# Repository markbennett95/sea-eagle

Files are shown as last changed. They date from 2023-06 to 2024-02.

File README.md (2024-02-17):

# BCA Sea Eagle Distortion

A multi-stage distortion pedal designed in conjunction with Nick Earle. The inspiration was a tight, heavy, Fall out boy-style rhythm tone. It features a dual-gang gain pot, an active 3-band EQ, and several pre-gain tone shaping switches. It is powered by our standard +-15V power supply, and uses a series of current sources to bias the various JFET stages.

## v1.0.0-build
1590BB enclosure with pots for Gain, Bass, Middle, Treble, Volume, and switches for bright, tight/fat, and high/low input gain.

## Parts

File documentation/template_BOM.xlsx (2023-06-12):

Weather Man v2.1.2 BOM - Nov 2021
Designation | Quantity | Designator
MMBFJ201 | 4 | Q1,Q2,Q3,Q4
47R | 1 | R30
1k | 5 | R4,R7,R20,R22,R25
2.7k | 2 | R6,R27
4.7k | 1 | R19
6.8k | 3 | R17,R29,R33
10k | 2 | R16,R21
12k | 1 | R9
33k | 2 | R11,R15
39k | 1 | R13
68k | 2 | R2,R34
100k | 2 | R31,R32
220k | 1 | R18
470k | 1 | R12
1M | 7 | R1,R3,R5,R10,R14,R24,R26
1N914 | 4 | D3,D1,D2,D4
1N4001 | 1 | D5
100pF | 3 | C1,C10,C12
100nF | 1 | C23
NJM4580 | 1 | U1
1nF | 2 | C3,C7
4.7nF | 1 | C16
6.8nF | 3 | C2,C21
10nF | 4 | C9,C8,C14,C20
47nF | 2 | C13,C17
0.1uF | 5 | C4,C5,C11,C15,C19
100uF | 2 | C22,C24
25kB | 2 | RV1,RV4
100kA | 1 | RV2
100kB | 2 | RV3,RV5
50kB | 1 | RV6
SW_SPDT_DIP | 1 | SW1
SW_SPDT | 1 | SW2

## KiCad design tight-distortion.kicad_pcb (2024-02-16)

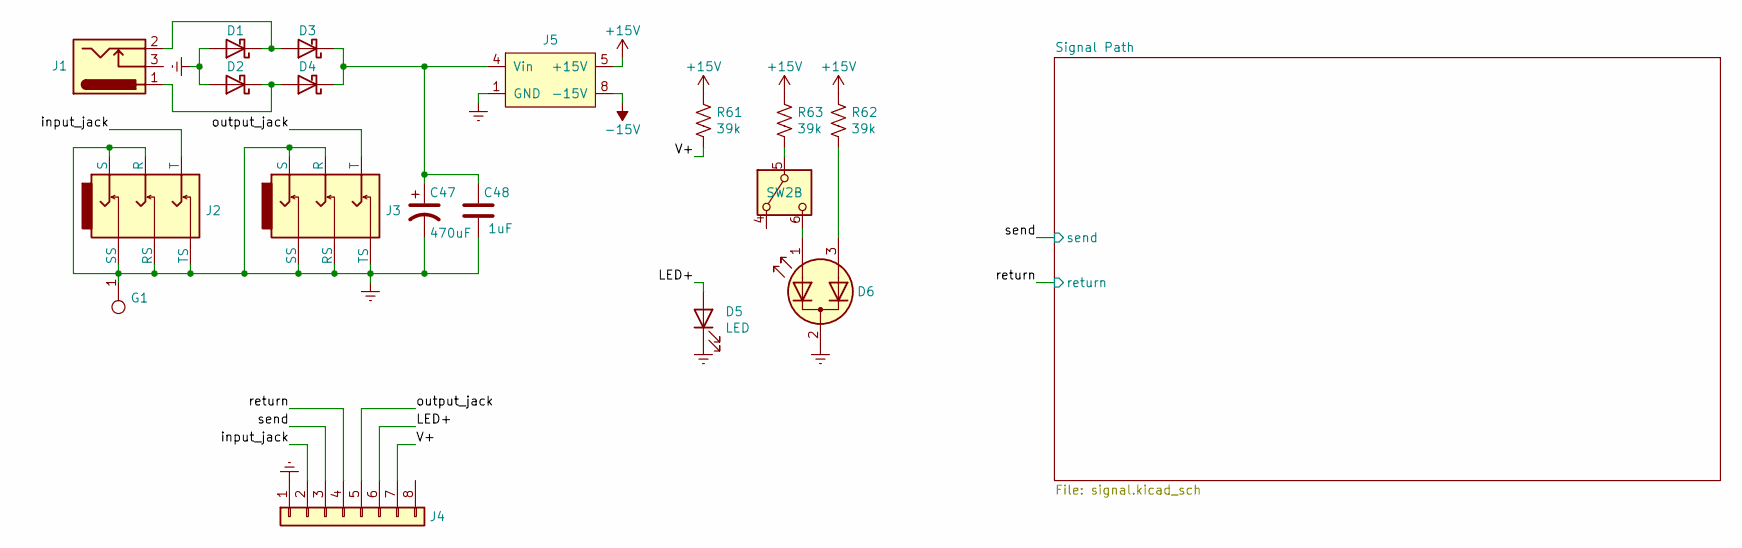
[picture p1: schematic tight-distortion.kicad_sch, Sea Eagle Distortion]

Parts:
C47: 470uF; CP_Radial_D8.0mm_P3.50mm
C48: 1uF; C_0805_2012Metric_Pad1.18x1.45mm_HandSolder
D1, D2, D3, D4: 1N5819; D_SOD-123
D5: LED; LED_D5.0mm
D6: LED_Dual_AAK; LED_D5.0mm-3
G1: GNDSpring; Keystone_628
J1: Barrel_Jack_Switch; DC_Jack_DC005
J2, J3: AudioJack_TRS; Rean_NYS215
J4: Conn_01x08; Pin_Header_Straight_1x08_Pitch2.54mm
J5: power-module; Power-module
R61, R62, R63: 39k; R_L3.6mm_D1.6mm_P5.00mm_Horizontal
SW2: SW_DPDT_x2; Pin_Header_Straight_1x06_Pitch2.54mm

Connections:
+15V: J5.5 (+15V), R61.1, R62.1, R63.1; also elsewhere on the board
-15V: J5.8 (-15V); also elsewhere on the board
/LED+: D5.2 (A), J4.6
/V+: J4.7, R61.2
/input_jack: J2.1 (T), J4.2
/output_jack: J3.1 (T), J4.5
/return: J4.4; also elsewhere on the board
/send: J4.3; also elsewhere on the board
Earth: C47.2, C48.2, D1.2 (A), D2.2 (A), D5.1 (K), D6.2 (K), G1.1, J2.2 (R), J2.3 (S), J2.4 (TS), J2.5 (RS), J2.6 (SS), J3.2 (R), J3.3 (S), J3.4 (TS), J3.5 (RS), J3.6 (SS), J4.1, J5.1 (GND); also elsewhere on the board
unnamed: D1.1 (K), D3.2 (A), J1.2
unnamed: D2.1 (K), D4.2 (A), J1.1
unnamed: C47.1, C48.1, D3.1 (K), D4.1 (K), J5.4 (Vin)
unnamed: D6.1 (A1), SW2.6 (C)
unnamed: D6.3 (A2), R62.2
unnamed: R63.2, SW2.5 (B)

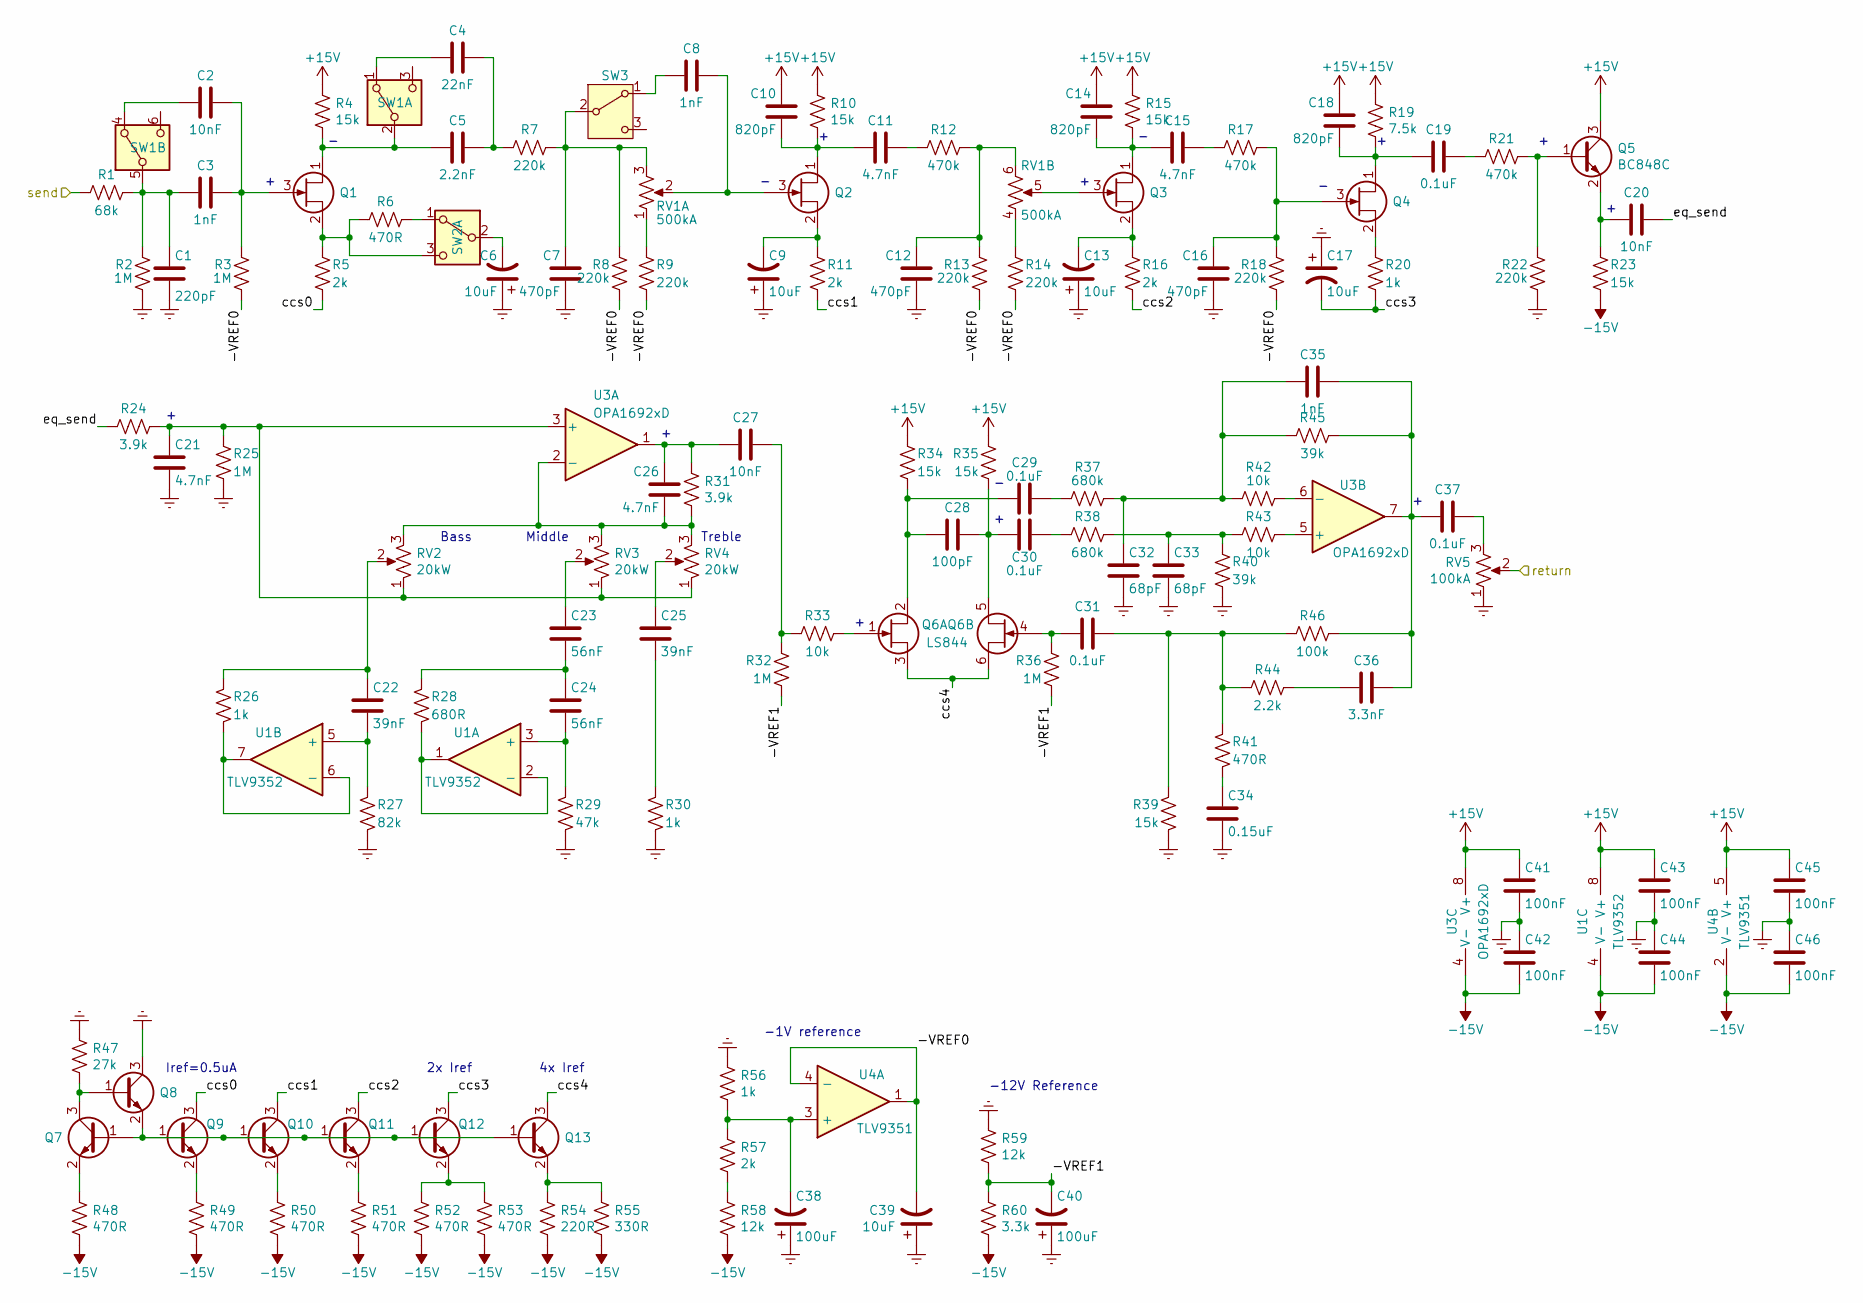
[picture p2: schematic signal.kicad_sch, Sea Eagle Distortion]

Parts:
C1: 220pF; C_0603_1608Metric_Pad1.08x0.95mm_HandSolder
C2, C20, C27: 10nF; C_Film_L7.2mm_W2.5mm_P5.00mm
C3, C8, C35: 1nF; C_Film_L7.2mm_W2.5mm_P5.00mm
C4: 22nF; C_Film_L7.2mm_W2.5mm_P5.00mm
C5: 2.2nF; C_Film_L7.2mm_W2.5mm_P5.00mm
C6, C9, C13, C17, C39: 10uF; CP_Radial_D4.0mm_P1.50mm
C7, C12, C16: 470pF; C_0603_1608Metric_Pad1.08x0.95mm_HandSolder
C10, C14, C18: 820pF; C_0603_1608Metric_Pad1.08x0.95mm_HandSolder
C11, C15, C21, C26: 4.7nF; C_Film_L7.2mm_W2.5mm_P5.00mm
C19, C29, C30, C31, C37: 0.1uF; C_Film_L7.2mm_W2.5mm_P5.00mm
C22, C25: 39nF; C_Film_L7.2mm_W2.5mm_P5.00mm
C23, C24: 56nF; C_Film_L7.2mm_W2.5mm_P5.00mm
C28: 100pF; C_0603_1608Metric_Pad1.08x0.95mm_HandSolder
C32, C33: 68pF; C_0603_1608Metric_Pad1.08x0.95mm_HandSolder
C34: 0.15uF; C_Film_L7.2mm_W2.5mm_P5.00mm
C36: 3.3nF; C_Film_L7.2mm_W2.5mm_P5.00mm
C38, C40: 100uF; CP_Radial_D6.3mm_P2.50mm
C41, C42, C43, C44, C45, C46: 100nF; C_0603_1608Metric_Pad1.08x0.95mm_HandSolder
Q1, Q2, Q3, Q4: MMBFJ202; SOT-23_Handsoldering
Q5, Q7, Q8, Q9, Q10, Q11, Q12, Q13: BC848C; SOT-23_Handsoldering
Q6: LS844; SOT-23-6_Handsoldering
R1: 68k; R_L3.6mm_D1.6mm_P5.00mm_Horizontal
R2, R3, R25, R32, R36: 1M; R_L3.6mm_D1.6mm_P5.00mm_Horizontal
R4, R10, R15, R23, R34, R35, R39: 15k; R_L3.6mm_D1.6mm_P5.00mm_Horizontal
R5, R11, R16: 2k; R_L3.6mm_D1.6mm_P5.00mm_Horizontal
R6, R41: 470R; R_L3.6mm_D1.6mm_P5.00mm_Horizontal
R7, R8, R9, R13, R14, R18, R22: 220k; R_L3.6mm_D1.6mm_P5.00mm_Horizontal
R12, R17, R21: 470k; R_L3.6mm_D1.6mm_P5.00mm_Horizontal
R19: 7.5k; R_L3.6mm_D1.6mm_P5.00mm_Horizontal
R20, R26, R30: 1k; R_L3.6mm_D1.6mm_P5.00mm_Horizontal
R24, R31: 3.9k; R_L3.6mm_D1.6mm_P5.00mm_Horizontal
R27: 82k; R_L3.6mm_D1.6mm_P5.00mm_Horizontal
R28: 680R; R_L3.6mm_D1.6mm_P5.00mm_Horizontal
R29: 47k; R_L3.6mm_D1.6mm_P5.00mm_Horizontal
R33, R42, R43: 10k; R_L3.6mm_D1.6mm_P5.00mm_Horizontal
R37, R38: 680k; R_L3.6mm_D1.6mm_P5.00mm_Horizontal
R40, R45: 39k; R_L3.6mm_D1.6mm_P5.00mm_Horizontal
R44: 2.2k; R_L3.6mm_D1.6mm_P5.00mm_Horizontal
R46: 100k; R_L3.6mm_D1.6mm_P5.00mm_Horizontal
R47: 27k; R_0603_1608Metric_Pad0.98x0.95mm_HandSolder
R48, R49, R50, R51, R52, R53: 470R; R_0603_1608Metric_Pad0.98x0.95mm_HandSolder
R54: 220R; R_0603_1608Metric_Pad0.98x0.95mm_HandSolder
R55: 330R; R_0603_1608Metric_Pad0.98x0.95mm_HandSolder
R56: 1k; R_0603_1608Metric_Pad0.98x0.95mm_HandSolder
R57: 2k; R_0603_1608Metric_Pad0.98x0.95mm_HandSolder
R58, R59: 12k; R_0603_1608Metric_Pad0.98x0.95mm_HandSolder
R60: 3.3k; R_0603_1608Metric_Pad0.98x0.95mm_HandSolder
RV1: 500kA; R_POT_DUAL
RV2, RV3, RV4: 20kW; R_POT
RV5: 100kA; R_POT
SW1: SW_DPDT_x2; SW_Toggle_DPDT_SolderLug
SW2: SW_DPDT_x2; Pin_Header_Straight_1x06_Pitch2.54mm
SW3: SW_SPDT; SW_Toggle_SPDT_SolderLug
U1: TLV9352; SOIC-8_3.9x4.9mm_P1.27mm
U3: OPA1692xD; SOIC-8_3.9x4.9mm_P1.27mm
U4: TLV9351; SOT-23-5

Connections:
+15V: C10.2, C14.2, C18.2, C41.1, C43.1, C45.1, Q5.3 (C), R4.1, R10.1, R15.1, R19.1, R34.1, R35.1, U1.8 (V+), U3.8 (V+), U4.5 (V+); also elsewhere on the board
-15V: C42.2, C44.2, C46.2, R23.2, R48.2, R49.2, R50.2, R51.2, R52.2, R53.2, R54.2, R55.2, R58.2, R60.2, U1.4 (V-), U3.4 (V-), U4.2 (V-); also elsewhere on the board
/Signal Path/-VREF0: C39.2, R3.2, R8.2, R9.2, R13.2, R14.2, R18.2, U4.1, U4.4 (-)
/Signal Path/-VREF1: C40.2, R32.2, R36.2, R59.2, R60.1
/Signal Path/ccs0: Q9.3 (C), R5.2
/Signal Path/ccs1: Q10.3 (C), R11.2
/Signal Path/ccs2: Q11.3 (C), R16.2
/Signal Path/ccs3: C17.2, Q12.3 (C), R20.2
/Signal Path/ccs4: Q6.3 (S1), Q6.6 (S1), Q13.3 (C)
/Signal Path/eq_send: C20.1, R24.1
/return: RV5.2; also elsewhere on the board
/send: R1.1; also elsewhere on the board
Earth: C1.2, C6.1, C7.1, C9.1, C12.1, C13.1, C16.1, C17.1, C21.1, C32.1, C33.1, C34.2, C38.1, C39.1, C40.1, C41.2, C42.1, C43.2, C44.1, C45.2, C46.1, Q8.3 (C), R2.2, R22.2, R25.2, R27.2, R29.2, R30.2, R39.2, R40.2, R47.1, R56.1, R59.1, RV5.1; also elsewhere on the board
unnamed: C4.1, C5.1, R7.1
unnamed: C11.1, R12.1
unnamed: C12.2, R12.2, R13.1, RV1.6
unnamed: C15.1, R17.1
unnamed: C19.1, R21.1
unnamed: C22.1, R26.1, RV2.2
unnamed: C23.1, RV3.2
unnamed: C23.2, C24.1, R28.1
unnamed: C25.1, RV4.2
unnamed: C25.2, R30.1
unnamed: C26.2, C27.2, R31.1, U3.1
unnamed: C27.1, R32.1, R33.1
unnamed: C29.1, R37.1
unnamed: C30.1, R38.1
unnamed: C31.1, R39.1, R41.1, R44.1, R46.1
unnamed: C32.2, C35.1, R37.2, R42.1, R45.1
unnamed: C33.2, R38.2, R40.1, R43.1
unnamed: C34.1, R41.2
unnamed: C35.2, C36.1, C37.2, R45.2, R46.2, U3.7
unnamed: C36.2, R44.2
unnamed: C37.1, RV5.3
unnamed: C5.2, Q1.1 (D), R4.2, SW1.2 (B)
unnamed: C2.1, C3.1, Q1.3 (G), R3.1
unnamed: Q1.2 (S), R5.1, R6.1, SW2.3 (C)
unnamed: C10.1, C11.2, Q2.1 (D), R10.2
unnamed: C8.1, Q2.3 (G), RV1.2 (5)
unnamed: C9.2, Q2.2 (S), R11.1
unnamed: C14.1, C15.2, Q3.1 (D), R15.2
unnamed: Q3.3 (G), RV1.5
unnamed: C13.2, Q3.2 (S), R16.1
unnamed: C18.1, C19.2, Q4.1 (D), R19.2
unnamed: C16.2, Q4.3 (G), R17.2, R18.1
unnamed: Q4.2 (S), R20.1
unnamed: Q5.1 (B), R21.2, R22.1
unnamed: C20.2, Q5.2 (E), R23.1
unnamed: C28.1, C29.2, Q6.2 (D1), R34.2
unnamed: Q6.1 (G1), R33.2
unnamed: C28.2, C30.2, Q6.5 (D2), R35.2
unnamed: C31.2, Q6.4 (G1), R36.1
unnamed: Q7.3 (C), Q8.1 (B), R47.2
unnamed: Q7.2 (E), R48.1
unnamed: Q9.2 (E), R49.1
unnamed: Q7.1 (B), Q8.2 (E), Q9.1 (B), Q10.1 (B), Q11.1 (B), Q12.1 (B), Q13.1 (B)
unnamed: Q10.2 (E), R50.1
unnamed: Q11.2 (E), R51.1
unnamed: Q12.2 (E), R52.1, R53.1
unnamed: Q13.2 (E), R54.1, R55.1
unnamed: R14.1, RV1.4
unnamed: R57.2, R58.1
unnamed: R9.1, RV1.1 (4)
unnamed: C7.2, R7.2, R8.1, RV1.3 (6), SW3.2 (B)
unnamed: C4.2, SW1.1 (A)
unnamed: C2.2, SW1.4 (A)
unnamed: C1.1, C3.2, R1.2, R2.1, SW1.5 (B)
unnamed: R6.2, SW2.1 (A)
unnamed: C6.2, SW2.2 (B)
unnamed: C8.2, SW3.1 (A)
unnamed: C24.2, R29.1, U1.3 (+)
unnamed: R28.2, U1.1, U1.2 (-)
unnamed: C22.2, R27.1, U1.5 (+)
unnamed: R26.2, U1.6 (-), U1.7
unnamed: C21.2, R24.2, R25.1, RV2.1, RV3.1, RV4.1, U3.3 (+)
unnamed: C26.1, R31.2, RV2.3, RV3.3, RV4.3, U3.2 (-)
unnamed: R43.2, U3.5 (+)
unnamed: R42.2, U3.6 (-)
unnamed: C38.2, R56.2, R57.1, U4.3 (+)

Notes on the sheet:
4x Iref
Treble
2x Iref
Bass
-1V reference
Iref=0.5uA
-12V Reference
Middle

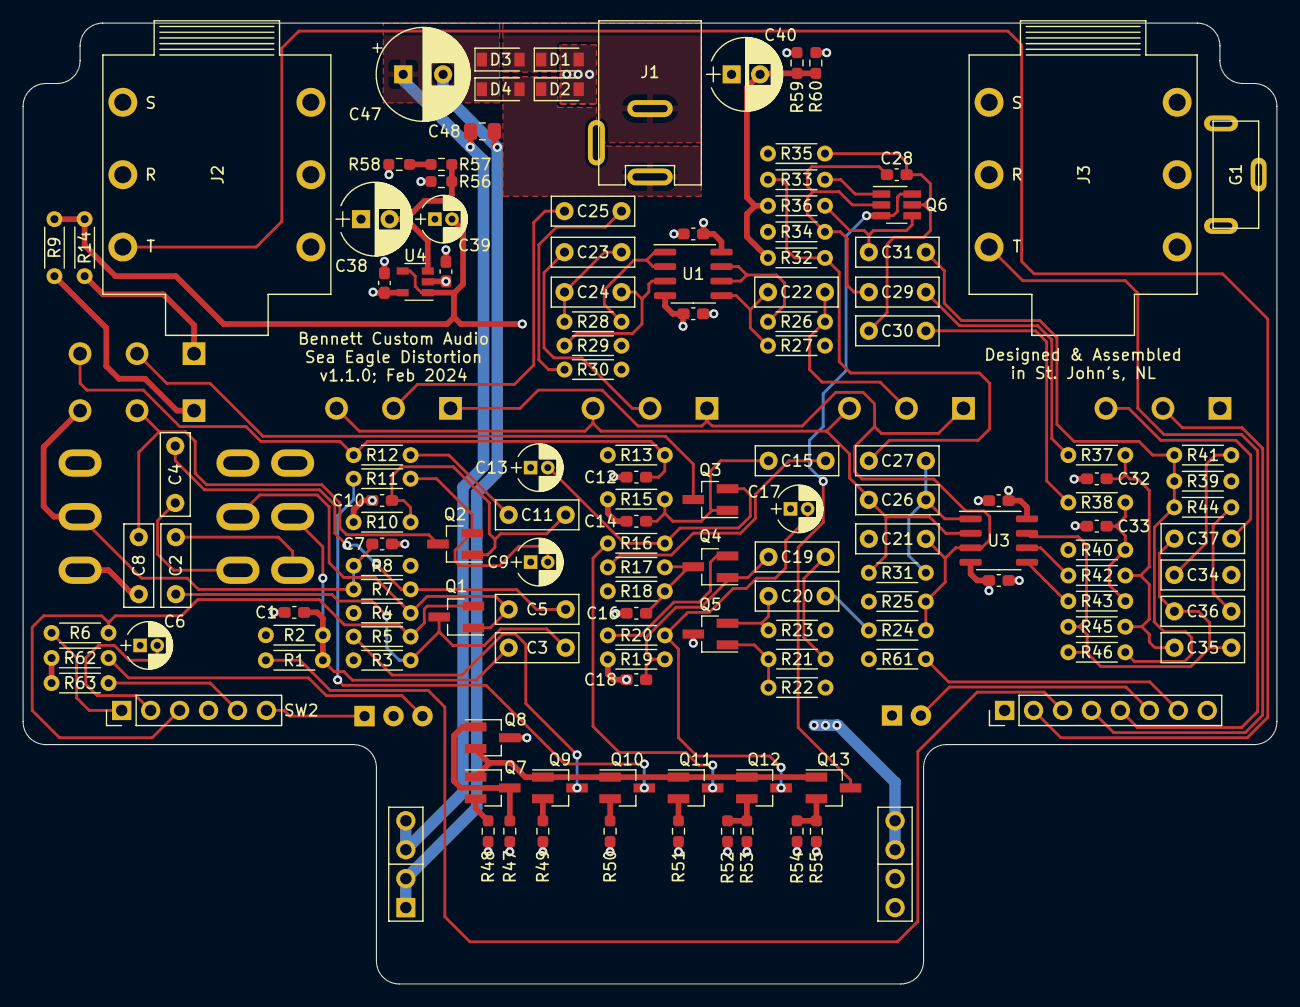
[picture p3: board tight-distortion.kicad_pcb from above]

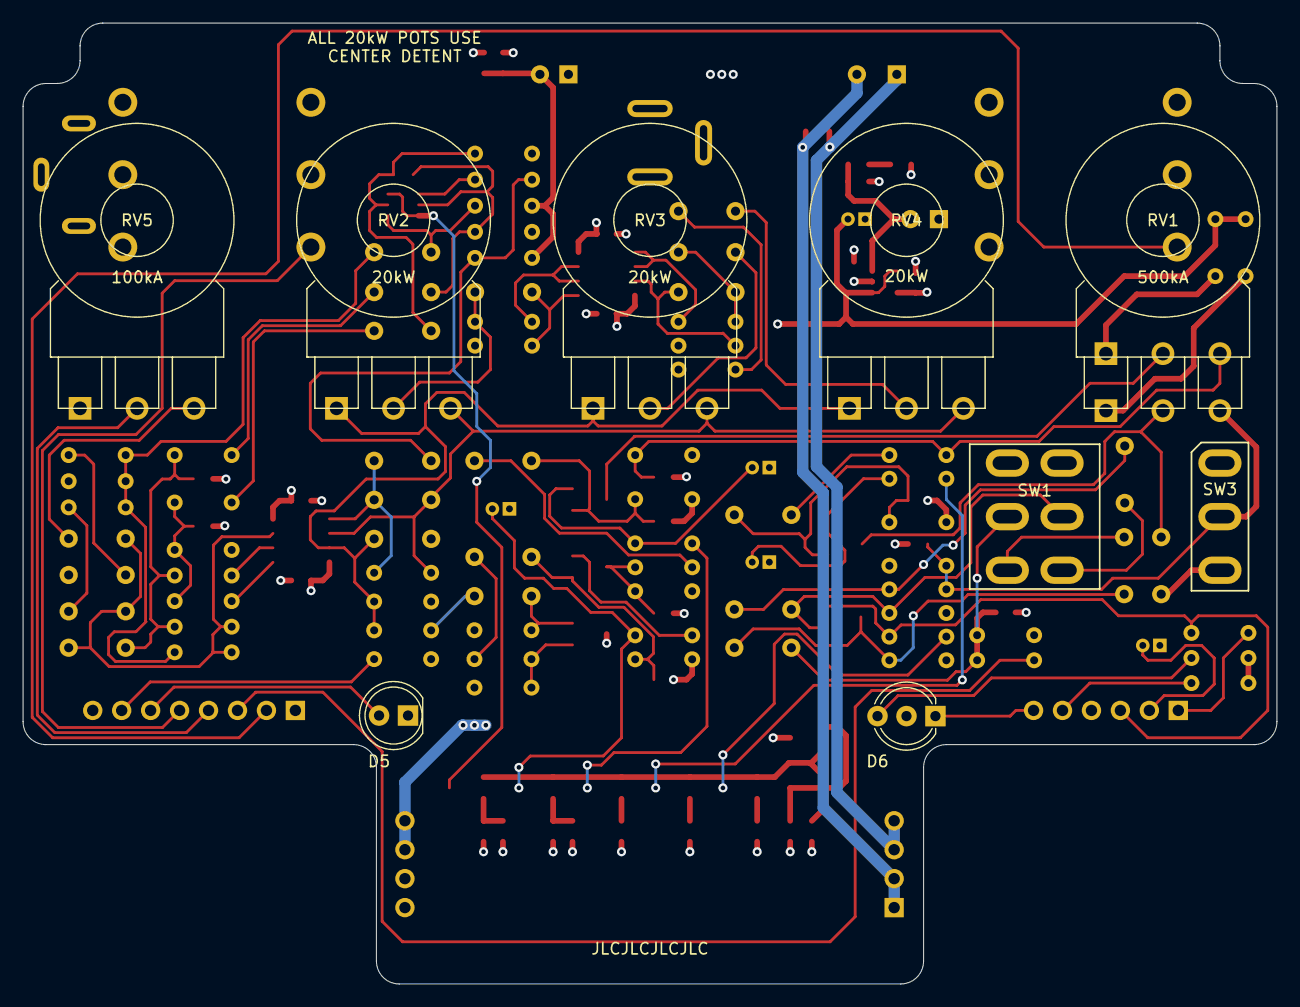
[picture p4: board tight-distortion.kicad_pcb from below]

Board: 4 copper layers, 110.0 x 84.3 mm, 147 parts (4 on the bottom side), 89 nets.

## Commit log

2023-06-12 updated file names
    [kicad-template_1590BB.kicad_pcb, tight-distortion.kicad_pcb, tight-distortion.sch]
2023-12-05 initial idea
    [tight-distortion.sch]
2023-12-09 first schematic draft
    [signal.sch, tight-distortion.sch]
2023-12-10 first PCB layout draft
    [signal.sch, tight-distortion.kicad_pcb, tight-distortion.sch]
2023-12-11 first pass of routing PCB
    [tight-distortion.kicad_pcb]
2023-12-11 corrected & finalized PCB
    [signal.sch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]
2024-01-12 development checkpoint
    [signal.sch, tight-distortion.kicad_pcb]
2024-01-24 as built with current PCB
    [signal.sch, tight-distortion.sch]
2024-02-02 updated project with new file formats
    [signal.kicad_sch, signal.sch, tight-distortion.kicad_sch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]
2024-02-02 start of PCB re-route
    [signal.kicad_sch, tight-distortion.kicad_pcb, tight-distortion.kicad_sch]
2024-02-07 first draft of PCB
    [signal.kicad_sch, tight-distortion.kicad_pcb]
2024-02-07 small schematic change
    [tight-distortion.kicad_pcb, tight-distortion.kicad_sch]
2024-02-16 final look at PCB
    [tight-distortion.kicad_pcb]
2024-02-16 generate gerbers
    [tight-distortion-B_Cu.gbr, tight-distortion-B_Mask.gbr, tight-distortion-B_Paste.gbr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]
